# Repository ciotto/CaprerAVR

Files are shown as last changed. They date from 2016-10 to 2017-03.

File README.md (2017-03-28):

# CaprerAVR

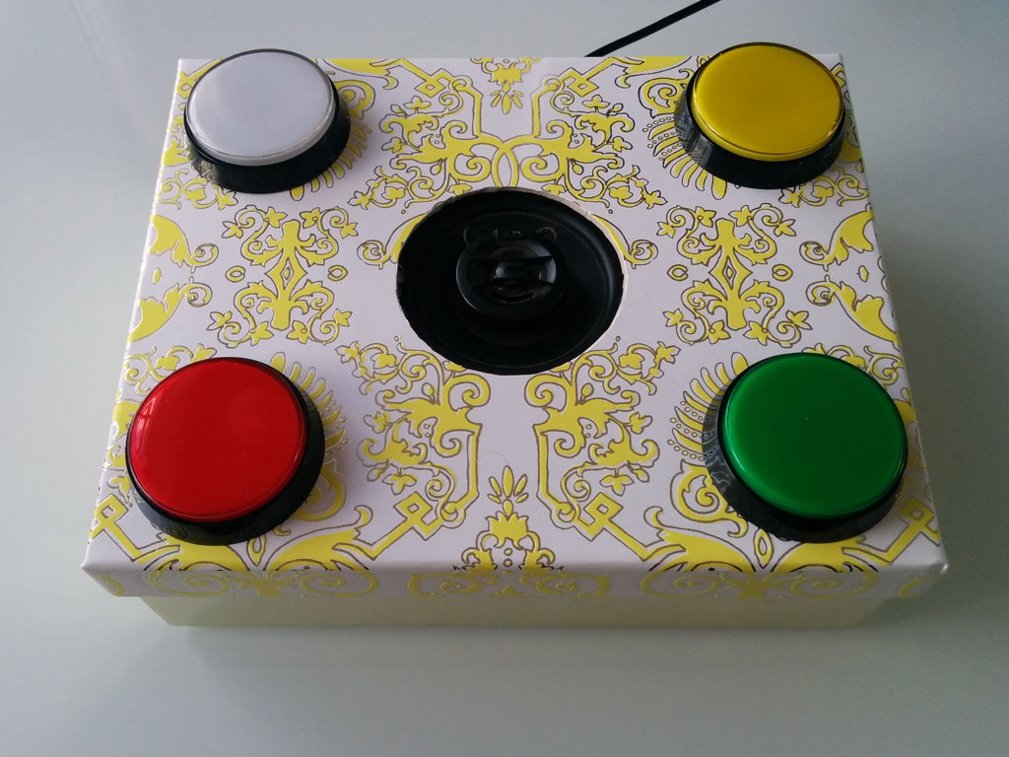
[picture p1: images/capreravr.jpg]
CaprerAVR


**CaprerAVR** is a crazy project for office survival, when you are in difficult, push the buzz button and **CaprerAVR** helps you!!

Dai dai dai

### Breadboar Schematic

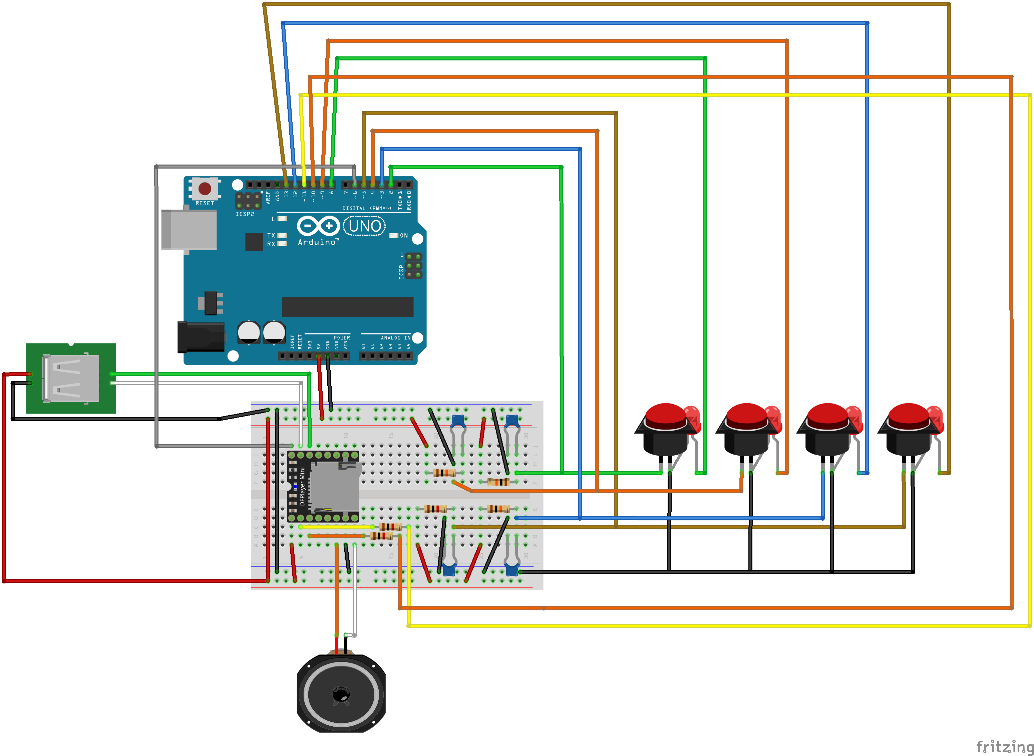
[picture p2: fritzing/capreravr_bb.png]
CaprerAVR


### Info

**CaprerAVR** is made using a **DFR0299** module drived by **Arduino** using the **[DFPlayer-Mini-mp3 library](https://github.com/DFRobot/DFPlayer-Mini-mp3/)** (if some functions are missing, try using [my version](https://github.com/ciotto/DFPlayer-Mini-mp3/))

### What you need

 - *1 x* [Arduino or compatible](http://www.aliexpress.com/item/UNO-R3-CH340G-ATmega328P-compatible-for-Arduino-UNO-R3/32523366108.html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,searchweb201602_5_10037_10017_405_507_10032,searchweb201603_11&btsid=4d84a66e-7b4c-4053-977e-ca0880699bd8)
 - *1 x* [DFR0299](http://it.aliexpress.com/item/1PCS-Mini-MP3-Player-Module-with-Simplified-Output-Speaker-for-Arduino-UNO/32271693515.html)
 - *4 x* [Buzz Button](http://it.aliexpress.com/item/1PC-LED-Light-60MM-Big-Round-Arcade-Video-Game-Player-Push-Button-Switch-Red-Plunger-Size/32645265359.html)
 - *1 x* microSD card
 - *2 x* 1k resistors
 - *4 x* 10k resistor
 - *4 x* ~100nF capacitator
 - *1 x* speaker
 - *some* mp3 samples

## ESP8266

It's possible to add networking capabilities to this awesome device thank to the ``ESP8266`` module.

There are many versions of the ESP8266 and I tested with the [ESP-12e](https://it.aliexpress.com/wholesale?catId=0&initiative_id=SB_20161009205149&SearchText=esp-12e).

ESP8266 family

Be careful, ESP8266 use a lot of current and work at **3.3V**, so if you have problem during scketch upload problably you don't have enought current (from specific *170mA*). Evaluate to use an external power source.

ESP-12e pinout

Follow instruction from this [repository](https://github.com/esp8266/Arduino) to enable the board on the Arduino IDE.

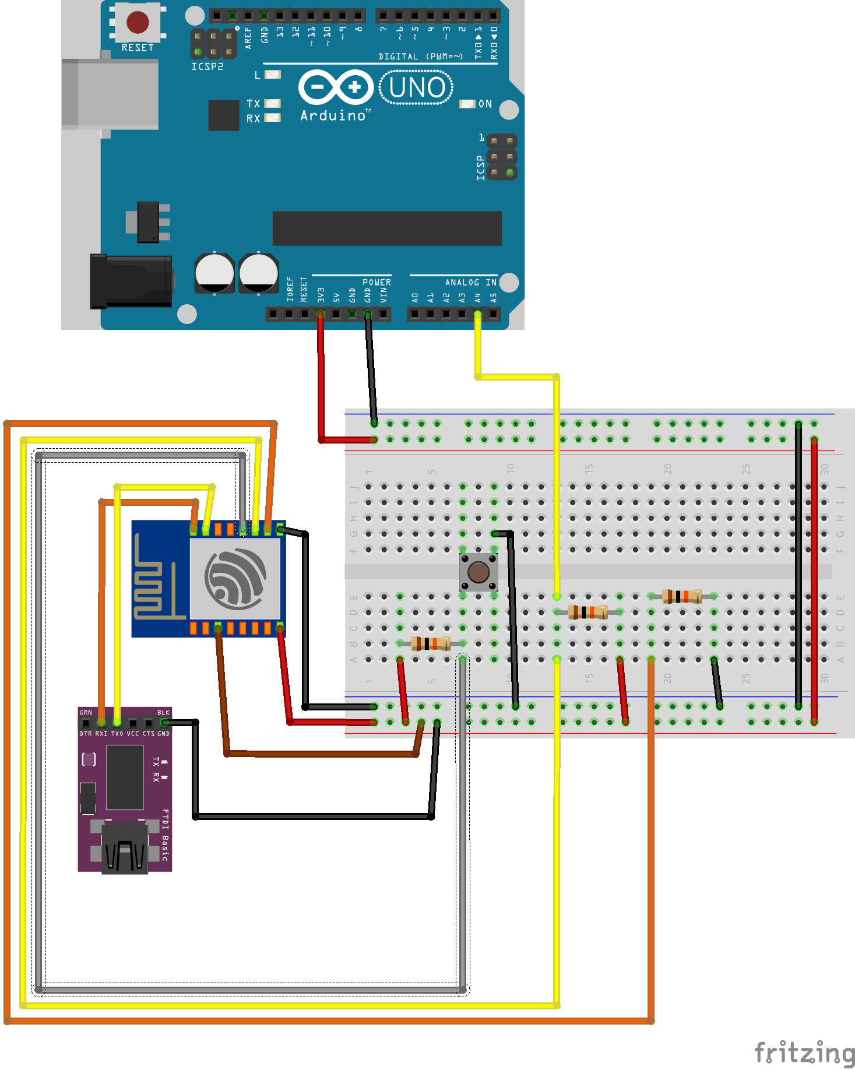
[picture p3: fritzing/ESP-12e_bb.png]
ESP-12e


In order to flash the firmware you need to set in programming mode the module: connect the pins ``GPIO0`` and ``GPIO15`` to **GND** and ``GPIO2 `` to **V<sub>CC</sub>**; after setup re-power. For normal operation instead connect ``GPIO0`` to **V<sub>CC</sub>**.

 Mode | GPIO0 | GPIO2 | GPIO15 
------|--------|--------|---------
 UART Download Mode (Programming) | 0 | 1 | 0 
 Flash Startup (Normal) | 1 | 1 | 0 
 SD-Card Boot | 0 | 0 | 1 

For some version of ``ESP8266`` (ex. ``ESP-01``) only ``GPIO0`` pin to **GND** is required.

At the [arduino/WifiWebServer/](arduino/WifiWebServer/) path you can find a simple web service that send commands on the ``GPIO 2`` serial.

From the serial console you can observe this output:

```
Connecting......

Connected to your-ssid
URL: http://192.168.1.11/
MDNS responder started
HTTP server started
```

### Compiling .html files

I made a simple *Python* tool that convert all **.html** pages in the [arduino/WifiWebServer/html/](arduino/WifiWebServer/html/) folder in **C headers** files with same naming.

###### Ex.

 HTML file | Header file | Header variable
------|--------|--------|---------
 html/index.html | index.h | INDEX 
 
###### Use

In order to use it, you can simple do this command:

```
	$ pip install -r requirements.txt
	$ python html_to_header.py
	Create arduino/WifiWebServer/index.h 
```

### What you need

 - *1 x* [ESP8266](https://it.aliexpress.com/item/2015-New-version-1PCS-ESP-12F-ESP-12E-upgrade-ESP8266-remote-serial-Port-WIFI-wireless-module/32510124042.html)
 - *1 x* [Push button](https://it.aliexpress.com/item/Promotion-Amico-100-Pcs-6x6x4-5mm-Panel-PCB-Momentary-Tactile-Tact-Push-Button-Switch-4-Pin/32563399489.html)
 - *4 x* 10k resistor
 - *1 x* [Serial adapter](https://it.aliexpress.com/item/3-3V-5V-FTDI-Basic-Program-Downloader-USB-to-TTL-FT232RL-For-Arduino/32409683938.html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)
 
## Links
 - [DFR0299 datasheet 1](http://www.picaxe.com/docs/spe033.pdf)
 - [DFR0299 datasheet 2](http://www.trainelectronics.com/Arduino/MP3Sound/TalkingTemperature/FN-M16P%20Embedded%20MP3%20Audio%20Module%20Datasheet.pdf)
 - [DFR0299 doc](http://www.dfrobot.com/wiki/index.php/DFPlayer_Mini_SKU:DFR0299)
 - [ESP-12e datasheet](https://mintbox.in/media/esp-12e.pdf)
 - [ESP8266 Bootloader Modes](https://zoetrope.io/tech-blog/esp8266-bootloader-modes-and-gpio-state-startup)
 - [DFRobotDFPlayerMini library](https://github.com/DFRobot/DFRobotDFPlayerMini/archive/1.0.1.zip)

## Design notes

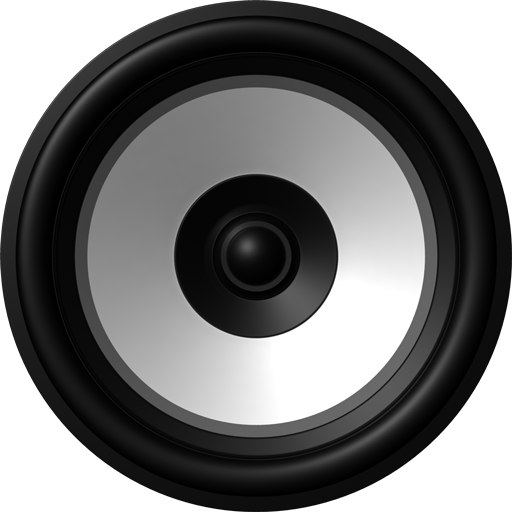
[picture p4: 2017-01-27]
images/speaker.png

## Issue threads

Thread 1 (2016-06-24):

Allow to playback files from an USB flash

gipi, 2016-06-24:
Following this [datasheet](http://www.trainelectronics.com/Arduino/MP3Sound/TalkingTemperature/FN-M16P%20Embedded%20MP3%20Audio%20Module%20Datasheet.pdf) seems possible to play file directly from an USB device connected to the pins names`USB+` and `USB-`.

I will try to implement this functionality if I find time at work ;)

ciotto, 2016-06-29:
I'm waiting for the cable.. XD

gipi, 2016-06-30:
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

you are right, I'll try tomorrow to take it.

gipi, 2017-03-11:
the cable is arrived, where is the functionality?

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

Closed 2017-03-29.

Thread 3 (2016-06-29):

Make an IoT sprizzibabbolo

gipi, 2016-06-29:
Could be possible to create a `REST` service with an `ESP8266` module like described [here](http://www.arduinesp.com/wifiwebserver).
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

ciotto, 2016-06-29:
Good idea Senpai..[from China with the van!](http://www.aliexpress.com/item/New-version-ESP-12E-replace-ESP-12-ESP8266-remote-serial-Port-WIFI-wireless-module/32643507082.html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,searchweb201602_5_10037_10017_405_507_10032,searchweb201603_11&btsid=371e2550-8376-4de0-824e-aa9579664510)

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

gipi, 2016-06-30:
It's possible to use [this](https://github.com/esp8266/Arduino) and compile/upload from the Arduino IDE

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

ciotto, 2017-04-13:
closed with commit 030a9ef5e2a472d446b17d5e15813cdf0348e7aa

Closed 2017-04-13.

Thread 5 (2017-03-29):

wrong tracks count after device change

ciotto, 2017-03-29:
For some reason when I call ``mp3.readFileCountsInFolder(folder)`` after ``mp3.outputDevice(device)`` the return value is wrong (always *256*).

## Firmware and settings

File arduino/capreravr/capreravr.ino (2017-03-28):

/*
  CaprerAVR

  Play a random mp3 sample in a DFR0299 microSD card slot.
  
  
  The circuit:
    * button LED attached from pin 13, 8, 9, 10 to ground
    * buzz buttons attached to pin 2, 3, 4, 5 from +5V
    * 10K resistors attached to pin 2, 3, 4, 5 from ground
    * DFR0299 mp3 player attached to pin 0, 1 (serial), 6 (busy) and power
    * speaker attached to DFR0299 pin 6 and 8
  
  * Note: on most Arduinos there is already an LED on the board
  attached to pin 13.
  
  
  created 2016
  by Ciotto <http://ci8.it>
  
  DFPlayer library are available here:
    https://github.com/DFRobot/DFRobotDFPlayerMini/archive/1.0.1.zip
  
 https://github.com/ciotto/CaprerAVR
 */

#include <SoftwareSerial.h>
#include "capreravr.h"
#include "CapreraUtilities.h"

SoftwareSerial mp3Serial(MP3_SERIAL_RX, MP3_SERIAL_TX);
SoftwareSerial wiFiSerial(WIFI_SERIAL_RX, WIFI_SERIAL_TX);

DFRobotDFPlayerMini mp3;

// variables
byte currentState = 0;                       // variable for storing the command/state
byte currentParameters = 0;                  // variable for storing extra data
uint16_t currentDevice = 0;                  // variable for storing current device (USB/FLASH)
boolean currentBusyState = !MP3_BUSY;
byte ledsState = 0;                          // variable for storing the LEDs status
byte tracks[BUTTONS_COUNT] = {0, 0, 0, 0};   // tracks in microSD
byte volume = 22;                            // the volume level
byte mode;                                   // the box mode

// http://stackoverflow.com/questions/109023/how-to-count-the-number-of-set-bits-in-a-32-bit-integer
int number_of_set_bits(int state) {
     state = state - ((state >> 1) & 0x55555555);
     state = (state & 0x33333333) + ((state >> 2) & 0x33333333);
     return (((state + (state >> 4)) & 0x0F0F0F0F) * 0x01010101) >> 24;
}

void play_folder (int folder, int track) {
  if (track <= 0) {
    track = random(1, tracks[folder - 1] + 1);
  }
  
  Serial.print("Play track ");
  Serial.print(track);
  Serial.print(" in folder ");
  Serial.println(folder);
  
  mp3.playLargeFolder(folder, track);
  
  // set LEDs state
  set_leds(BUTTONS[folder - 1]);
}

void stop () {
  Serial.println("Stop");
      
  // stop
  mp3.pause();

  // set LEDs state
  set_leds(0);
}

void set_mode (int m) {
  mode = m;
  
  // Play mode sound
  mp3.playLargeFolder(MODE_FOLDER, mode);
  
  Serial.print("Select mode ");
  Serial.println(mode, BIN);
}

void set_volume(int v) {
  Serial.print("Set volume to ");
  Serial.println(v);
  
  // Set volume (value 0~30)
  mp3.volume(v);
}

int set_leds (int state) {
  if (state == 0) {
    state = mode;
  }

  if (ledsState != state) {
    ledsState = state;
    
    for (int i=0; i < BUTTONS_COUNT; i++) {
      // turn LEDs on if related button pressed:
      digitalWrite(LEDS_PIN[i], (state & (1 << i)) >> i);
    }
  }
}

void setup_device(uint16_t device) {
  Serial.print("Setup device ");
  Serial.print(device);
  Serial.println(".");
  
  currentDevice = device;
  mp3.outputDevice(device);

  for (int i=0; i < BUTTONS_COUNT; i++) {
    // Query the total number of microSD card files
    tracks[i] = mp3.readFileCountsInFolder(i + 1);

    Serial.print("Find ");
    Serial.print(tracks[i]);
    Serial.print(" tracks in folder 0");
    Serial.print(i + 1);
    Serial.println(".");
  }
}

void clean_buffers() {
  while (wiFiSerial.available()) {
    wiFiSerial.read();
    delay(10);
  }
  while (Serial.available()) {
    Serial.read();
    delay(10);
  }
}

void setup() {
  // Init serial
  Serial.begin (9600);
  while (!Serial);

  mp3Serial.begin (9600);
  wiFiSerial.begin (9600);

  mp3Serial.listen();

  Serial.println("Starting CaprerAVR...\n");

  while (!mp3.begin(mp3Serial)) {
    Serial.println("Unable to begin DFPlayer Mini");
    delay(1000);
  }
  Serial.println("DFPlayer Mini online.");

  for (int i=0; i < BUTTONS_COUNT; i++) {
    // initialize the LED pin as an output:
    pinMode(LEDS_PIN[i], OUTPUT);

    // initialize the buzz button pin as an input:
    pinMode(BUTTONS_PIN[i], INPUT);
  }

  // Set volume (value 0~30)
  set_volume(volume);
  // Set device to microSD
  setup_device(DEFAULT_DEVICE);

  wiFiSerial.listen();

  // Set default mode
  set_mode(DEFAULT_MODE);
  delay(100);

  // Reset buffers
  clean_buffers();

  // Blink LEDs
  set_leds(B1111);
  delay(500);
  set_leds(B0000);
}

void loop() {
  // Read busy state
  boolean newBusyState = digitalRead(BUSY_PIN);

  // Read serial command
  int serialCommand = 0;
  byte serialParameters = 0;
  char buffer[13] = {'0', '0', '0', '0','0', '0', '0', '0', '0', '0', '0', '0', '\0'};

  if (Serial.available() >= COMMANDS_SIZE) {
    // USB serial
    for (byte i=0; i < COMMANDS_SIZE; i++) {
      // read the incoming byte:
      buffer[i] = Serial.read();
    }

    Serial.print("Serial command received: ");
    Serial.println(buffer);
  }else if (wiFiSerial.available() >= COMMANDS_SIZE) {
    // WiFI serial
    for (byte i=0; i < COMMANDS_SIZE; i++) {
      // read the incoming byte:
      buffer[i] = wiFiSerial.read();
    }

    Serial.print("WiFi command received: ");
    Serial.println(buffer);
  } 
  clean_buffers();

  serialCommand = bitString2Int(buffer, COMMANDS_SIZE + 1);
  serialParameters = serialCommand >> 4;
  serialCommand &= (B00000000 << 8) | B00001111;

  // Read buttons state
  byte buttonsState = 0;
  for (byte i=0; i < BUTTONS_COUNT; i++) {
    // read the state of the buzz button
    byte buttonState = !digitalRead(BUTTONS_PIN[i]);
    buttonsState |= (buttonState << i);
  }

  if (buttonsState) {
    currentState = buttonsState;
  } else {
    currentParameters = serialParameters;
    currentState = serialCommand;
  }

  byte bitsCount = number_of_set_bits(currentState);

  // Check if the a buzz buttons is pressed
  if (bitsCount == 1) { 
    if (newBusyState == !MP3_BUSY) {
      // MODE2 prevent play folder 4
      if (currentState == BUTTON4 && mode == MODE2) {
        currentState = BUTTON3;

      // MODE3 play only folder 4
      }else if (bitsCount == 1 && mode == MODE3) {
        currentState = BUTTON4;

      // MODE4 play random folder
      }else if (bitsCount == 1 && mode == MODE4) {
        currentState = BUTTONS[random(0, BUTTONS_COUNT)];
      }

      // Button 1 pressed
      //   X  O
      //   O  O
      if (currentState == BUTTON1) {
        play_folder(1, currentParameters);
        
      // Button 2 pressed
      //   O  X
      //   O  O
      } else if (currentState == BUTTON2) {
        play_folder(2, currentParameters);
        
      // Button 3 pressed
      //   O  O
      //   X  O
      } else if (currentState == BUTTON3) {
        play_folder(3, currentParameters);

      // Button 4 pressed
      //   O  O
      //   O  X
      } else {
        play_folder(4, currentParameters);
      }
    
    // Stop if playing
    } else {
      stop();
    }

    delay(200);
    
  // More that one button pressed (special controls)
  } else if (bitsCount > 1) {
    // Change device
    //   O  X
    //   O  X
    if (currentState == CHANGE_DEVICE) {
      if (currentDevice == DFPLAYER_DEVICE_SD) {
        setup_device(DFPLAYER_DEVICE_U_DISK);
      } else {
        setup_device(DFPLAYER_DEVICE_SD);
      }

    // Volume UP
    //   X  X
    //   X  O
    } else if (currentState == VOLUME_UP) {
      if (volume < 30) {
        volume++;
      }
    
      set_volume(volume);
      if (newBusyState == !MP3_BUSY) {
        mp3.playLargeFolder(SOUND_FOLDER, VOLUME_SOUND);
      }

    // Volume DOWN
    //   X  O
    //   X  X
    } else if (currentState == VOLUME_DOWN) {
      if (volume > 0) {
        volume--;
      }
    
      set_volume(volume);
      if (newBusyState == !MP3_BUSY) {
        mp3.playLargeFolder(SOUND_FOLDER, VOLUME_SOUND);
      }

    // Change mode
    //   X  X
    //   X  X
    } else if (currentState == MODE_SWITCH && newBusyState == !MP3_BUSY) {
      byte m = MODE1;
      if (currentParameters && currentParameters <= MODES_COUNT) {
        m = MODES[currentParameters - 1];
      } else {
        if (mode == MODE1) {
          m = MODE2;
        } else if (mode == MODE2) {
          m = MODE3;
        } else if (mode == MODE3) {
          m = MODE4;
        }
      }
      set_mode(m);
    }

    delay(500);
  }

  // Check if DFR0299 busy state change to not busy
  if (newBusyState == !MP3_BUSY && currentBusyState != newBusyState) {
    set_leds(0);
  }
  currentBusyState = newBusyState;

  delay(100);
}

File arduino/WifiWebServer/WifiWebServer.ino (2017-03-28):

#include <ESP.h>
#include <ESP8266WiFi.h>
#include <WiFiClient.h>
#include <ESP8266WebServer.h>
#include <ESP8266mDNS.h>
#include "capreravr.h"
#include "index.h"
#include "WiFiConfig.h"
#include "CapreraUtilities.h"


//IPAddress ip(192, 168, 1, 9);

ESP8266WebServer server(80);

const int LED_PIN = 13;

boolean handleCommands() {
  int command = 0;
  int track = 0;
  if (!server.arg("track").equals("")) {
    track = server.arg("track").toInt();
  }

  if (server.arg("volume").equals("up")) {
    command = VOLUME_UP;
  }else if (server.arg("volume").equals("down")) {
    command = VOLUME_DOWN;
  }else if (server.arg("button").equals("1")) {
    command = BUTTON1 | (track << 4);
  }else if (server.arg("button").equals("2")) {
    command = BUTTON2 | (track << 4);
  }else if (server.arg("button").equals("3")) {
    command = BUTTON3 | (track << 4);
  }else if (server.arg("button").equals("4")) {
    command = BUTTON4 | (track << 4);
  }else if (server.arg("mode").equals("1")) {
    command = MODE_SWITCH | (1 << 4);
  }else if (server.arg("mode").equals("2")) {
    command = MODE_SWITCH | (2 << 4);
  }else if (server.arg("mode").equals("3")) {
    command = MODE_SWITCH | (3 << 4);
  }else if (server.arg("mode").equals("4")) {
    command = MODE_SWITCH | (4 << 4);
  }
  // Send command over Serial1
  if (command != 0) {
    char buffer[COMMANDS_SIZE + 1];
    
    Serial1.print(int2BitString(buffer, command, COMMANDS_SIZE + 1));
    
    return true;
  }

  return false;
}

void handleJson() {
  digitalWrite(LED_PIN, 1);

  boolean sent = handleCommands();
  
  server.send(200, "application/json", sent ? "true" : "false");
  digitalWrite(LED_PIN, 0);
}

void handleRoot() {
  digitalWrite(LED_PIN, 1);

  handleCommands();

  int bufferSize = 400;

  server.send(200, "text/html", INDEX);
  digitalWrite(LED_PIN, 0);
}

void handleNotFound(){
  digitalWrite(LED_PIN, 1);
  String message = "File Not Found\n\n";
  message += "URI: ";
  message += server.uri();
  message += "\nMethod: ";
  message += (server.method() == HTTP_GET)?"GET":"POST";
  message += "\nArguments: ";
  message += server.args();
  message += "\n";
  for (uint8_t i=0; i<server.args(); i++){
    message += " " + server.argName(i) + ": " + server.arg(i) + "\n";
  }

  server.send(404, "text/plain", message);
  digitalWrite(LED_PIN, 0);
}

void setup(void){
  pinMode(LED_PIN, OUTPUT);
  digitalWrite(LED_PIN, 0);
  Serial.begin(115200);
  Serial1.begin(9600);
  WiFi.begin(SSID, PASSWORD);
  Serial.println("");

  // Wait for connection
  Serial.print("Connecting..");
  while (WiFi.status() != WL_CONNECTED) {
    delay(500);
    Serial.print(".");
    if (WiFi.status() == WL_NO_SSID_AVAIL) {
      Serial.println("SSID not available...");
      //ESP.reset();
    }
  }
  Serial.println("");
  Serial.print("Connected to ");
  Serial.println(SSID);
  Serial.print("URL: http://");
  Serial.print(WiFi.localIP());
  Serial.println("/");

  if (MDNS.begin("esp8266")) {
    Serial.println("MDNS responder started");
  }

  server.on("/", handleRoot);
  server.on("/json", handleJson);

  server.on("/inline", [](){
    server.send(200, "text/plain", "this works as well");
  });

  server.onNotFound(handleNotFound);

  server.begin();
  Serial.println("HTTP server started");
}

void loop(void){
  server.handleClient();
}

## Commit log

2016-06-20 add base Arduino code
2016-06-20 move Arduino project
2016-06-21 add schema
    [capreravr.fzz]
2016-06-27 update for 4 buttons layout
2016-06-27 update schema
    [capreravr.fzz]
2016-06-27 read DFR0299 busy state - light the LEDs if is playing - stop playing if some button is pressed
2016-06-28 blink leds on startup
2016-06-28 play random sound in different folder for different button
2016-06-28 add volume adjust from buttons
2016-06-29 use SoftwareSerial instead of Serial1 (now works on Arduino Uno)
2016-07-11 update LEDs pins
2016-07-14 factorize code - special controls don't stop current track - fix LEDs state - add change volume sound
    [capreravr.ino]
2016-10-07 add software serial over pin 18/19
2017-01-20 update samples
2017-01-20 update led pins
2017-01-20 reset buffer at start
    [capreravr.ino]
2017-01-20 change buttons on/off levels
2017-01-20 update schemas
    [ESP-12e.fzz, capreravr.fzz]
2017-03-28 change library (from DFPlayer-Mini-mp3 to DFRobotDFPlayerMini)
    [capreravr.fzz]
2017-03-28 select track from web interface
